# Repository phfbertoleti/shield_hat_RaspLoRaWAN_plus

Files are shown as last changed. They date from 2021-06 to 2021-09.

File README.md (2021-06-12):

# Repositório - Shield/hat RaspLoRaWAN+

Este é o repositório oficial do shield/hat RaspLoRaWAN+. Este sheild/hat fornece à Raspberry Pi, com o uso de um Heltec ESP32 WiFi LoRa, os seguintes recursos:

* Envio (uplink) e recepção (downlink) de mensagens LoRaWAN (já configurado para operar com a rede da ATC no Brasil)
* Leitura de até 3 canais ADC (tensão máxima: 3V3)
* Controle de uma saída analógica (via DAC, com tensão máxima de 3V3)
* Interação com dispositivos (sensores, por exemplo) I²C, com nível de tensão de 3V3
* Escrita, linha a linha, no display OLED do Heltec ESP32 WiFi LoRa

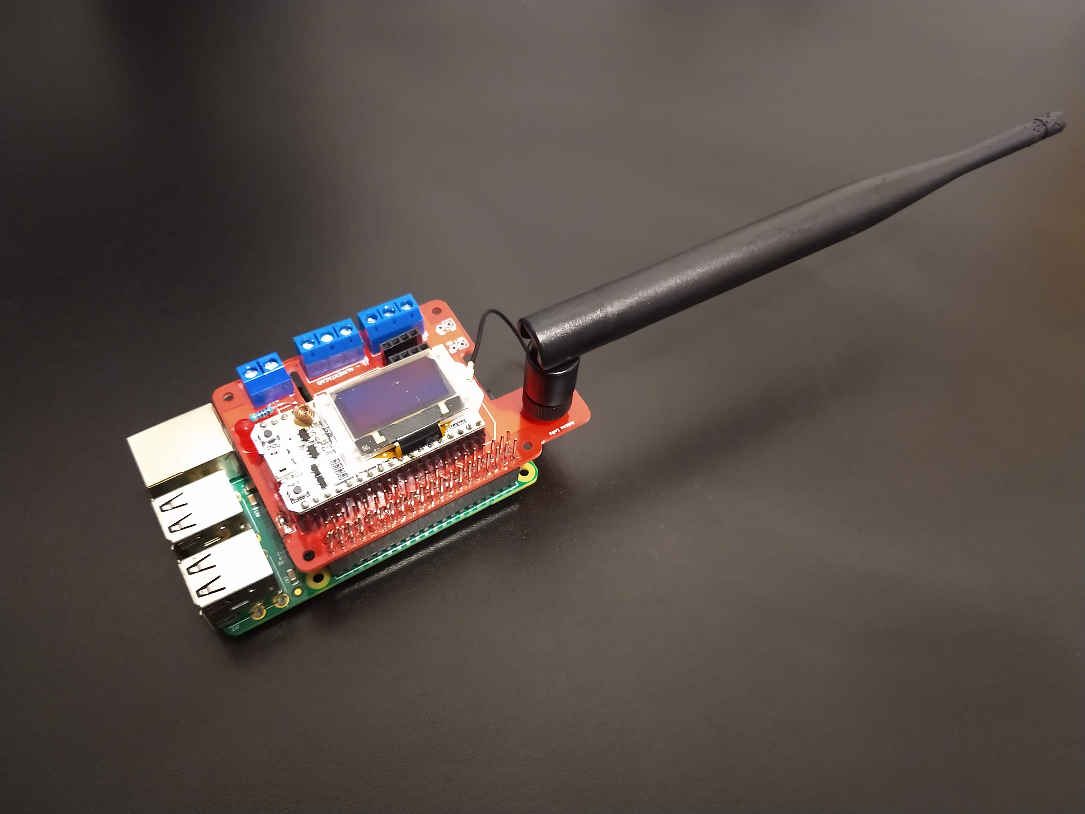
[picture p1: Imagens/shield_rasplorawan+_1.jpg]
Foto do shield/hat RaspLoraWAN+


## Funcionamento e estrutura básica dos códigos-fonte

Este shield/hat funciona com a Raspberry Pi enviando e recebendo mensagens ao Heltec ESP32 WiFi LoRa via UART (115200/8/N/1). Para tal, do lado da Raspberry Pi, é disponível um serviço chamado recebe_envia_dados_uart, totalmente escrito em C para máxima eficiência e otimização. Já do lado do Heltec ESP32 WiFi LoRa, é utilizado um software embarcado escrito na Arduino IDE, fazendo uso de FreeRTOS.

Para interagir com o serviço, é utilizado o protocolo MQTT como IPC (Inter-Processes Communication), com um broker MQTT rodando internamente na Raspberry Pi. Dessa forma, é possível interagir com todas as funcionalidades fazendo publish e subscribe em tópicos MQTT específicos.

A estrutura básica dos códigos-fonte é:

* *Pasta ESP32:* software embarcado a ser gravado no Heltec ESP32 WiFi LoRa. Antes de compilar e gravar, é preciso somente colocar as chaves LoRaWAN no arquivo LORAWAN_defs.h
* *Pasta Raspberry/recebe_envia_dados_uart:* serviço de comunicação UART entre Raspberry Pi e Heltec ESP32 WiFi LoRa, assim como IPC com MQTT
* *Pasta Raspberry/unit_files:* unit files para habilitar o serviço no systemd
* *Pasta Raspberry/Exemplos_Python:* exemplos (em Python 3.X) que exploram todos os recursos da placa
* *Pasta Hardware:* projeto completo (esquemático, layout e gerber files) de hardware do shield/hat

## Compatibilidade

Este shield/hat e seu respectivo software é compatível com todas Raspberries Pi com header de expansão de 40 pinos, como por exemplo:

* Raspberry Pi 3B
* Raspberry Pi 3B+
* Raspberry Pi Zero
* Raspberry Pi Zero W
* Raspberry Pi 4
* Raspberry Pi A+
* etc.

## Instalação dos softwares necessários na Raspberry Pi

Para instalar todos os softwares e dependências necessários na Raspberry Pi, siga o procedimento abaixo:

1. Se sua Raspberry Pi não possuir acesso à Internet, faça-a ter. 
Isso é necessário para a instalação das dependências.
2. Clone este repositório no home (/home/pi)
3. Na pasta do repositório, execute o script instala_tudo.sh como super-usuário:

```
sudo instala_tudo.sh
```

4. Aguarde a instalação automática. No fim do processo, o serviço que comunica com o shield/hat via UART e demais processos (IPC) via MQTT estará rodando. Para verificar a execução deste serviço, utilize o comando abaixo:

```
sudo systemctl status recebe_envia_esp32.service
```

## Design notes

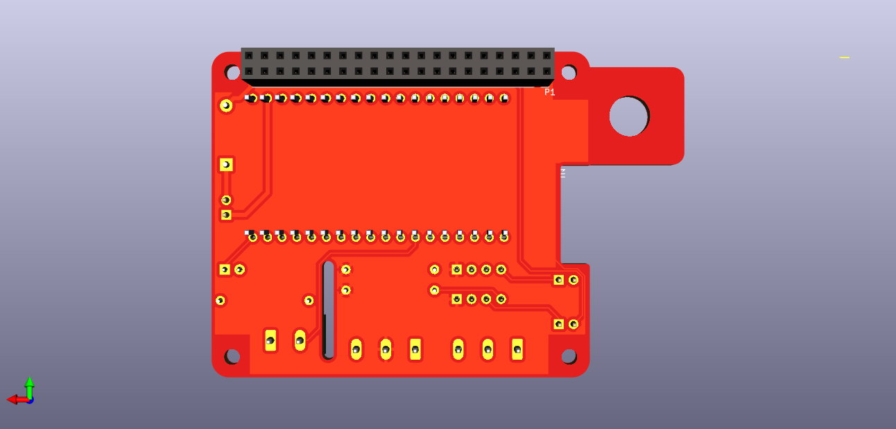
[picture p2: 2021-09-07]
Hardware/rasp_heltec_lora_hat/pcd_3d/rasp_heltec_lora_hat_bottom.png

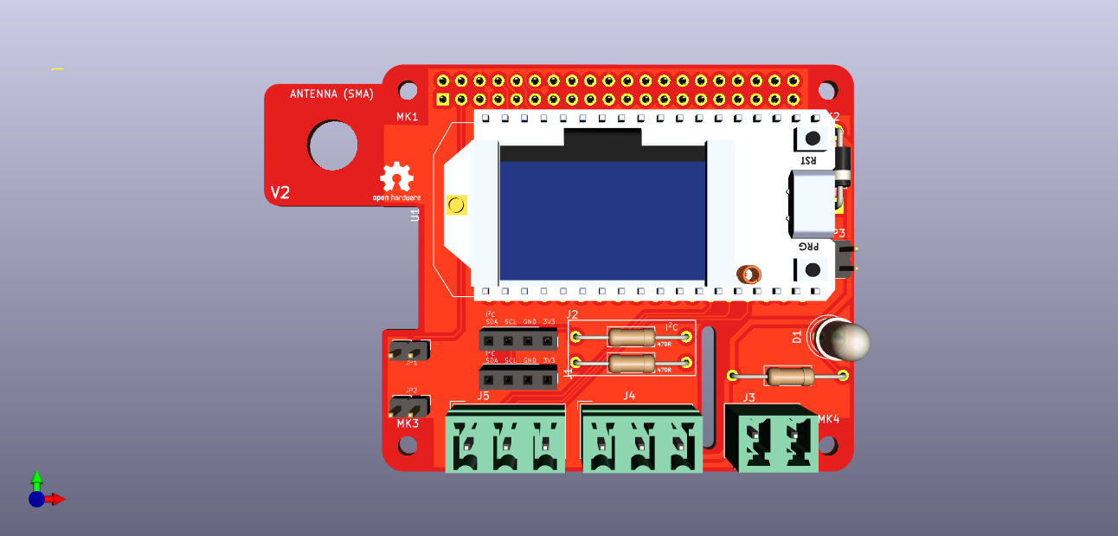
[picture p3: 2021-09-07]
Hardware/rasp_heltec_lora_hat/pcd_3d/rasp_heltec_lora_hat_top.png

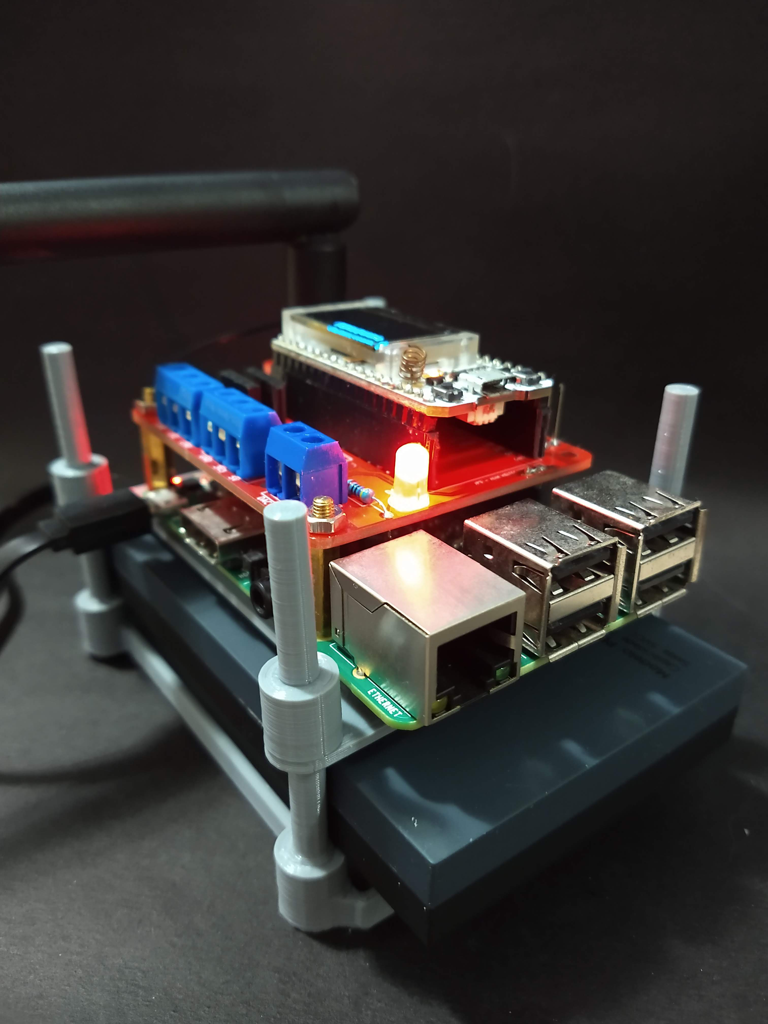
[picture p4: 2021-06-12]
Imagens/sheild_rasplorawan+_2.jpg

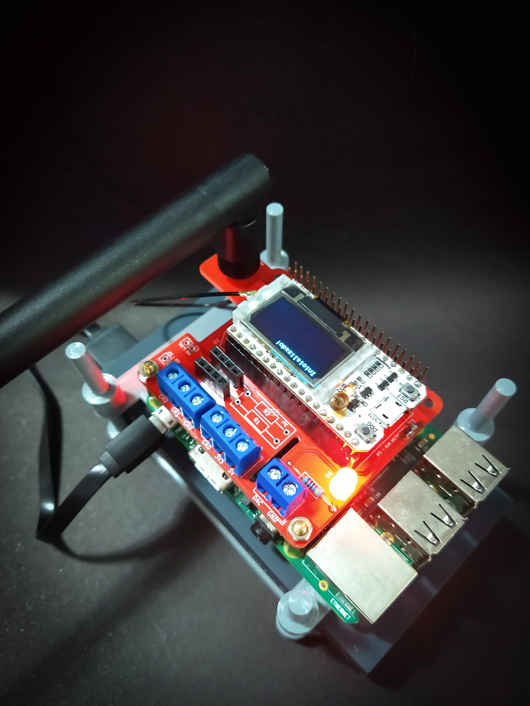
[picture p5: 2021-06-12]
Imagens/sheild_rasplorawan+_4.jpg

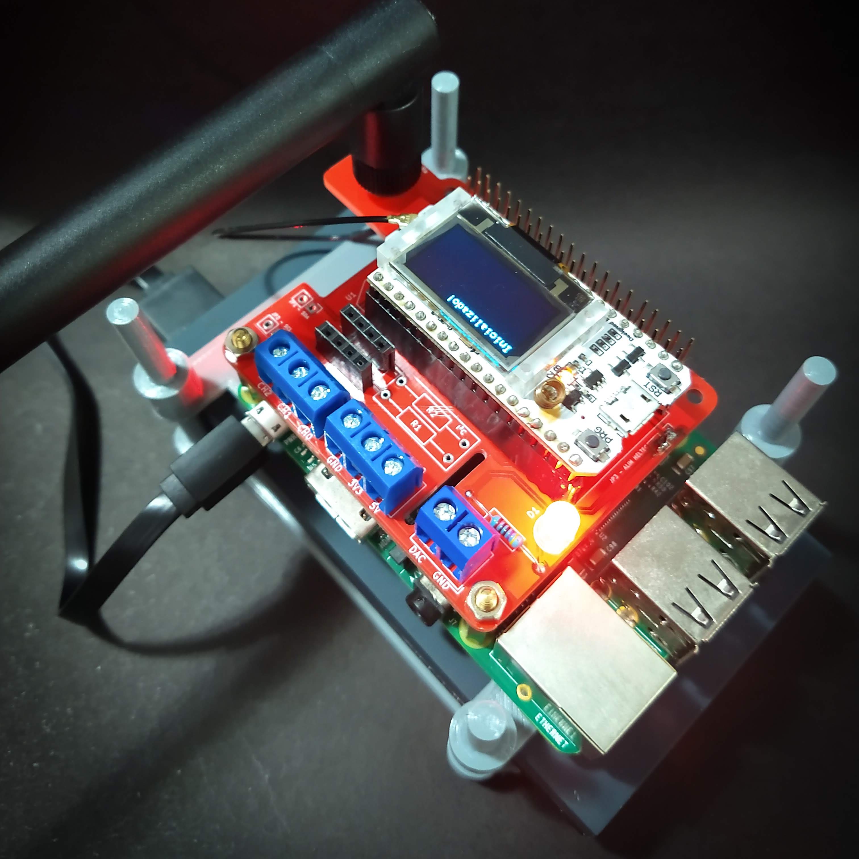
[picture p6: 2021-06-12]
Imagens/sheild_rasplorawan+_5.jpg

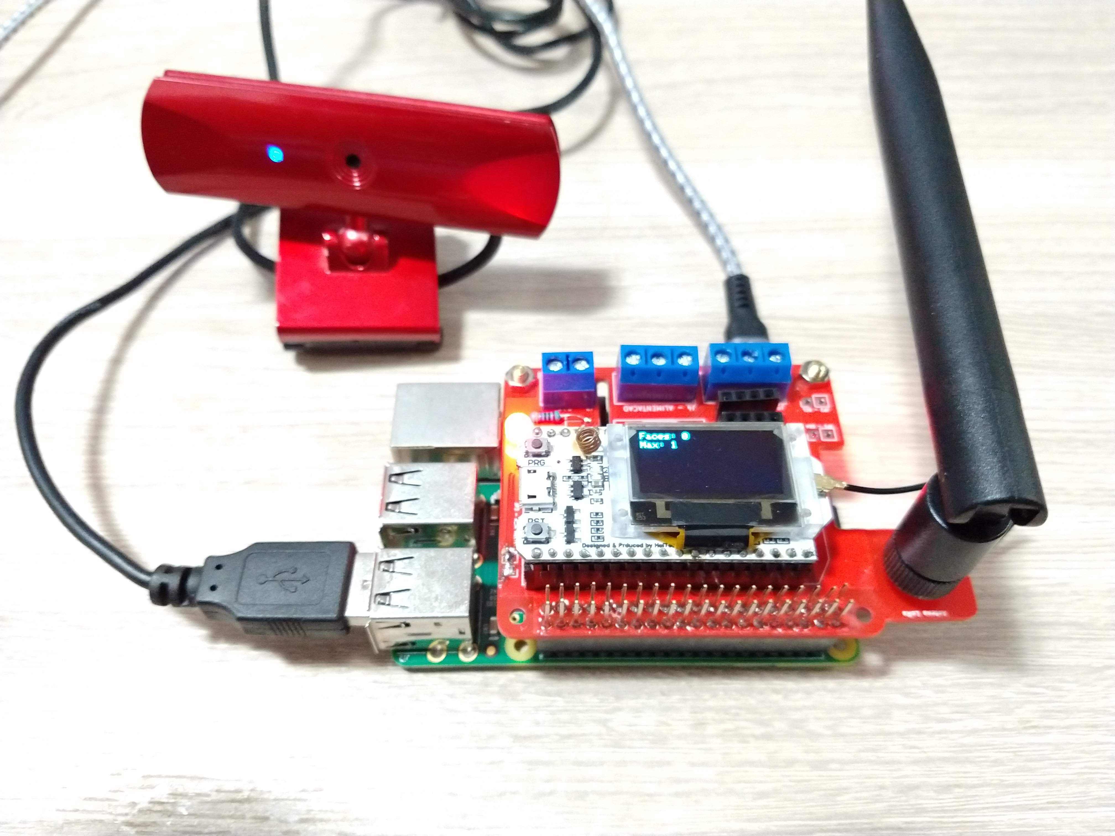
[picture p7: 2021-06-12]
Imagens/shield_rasplorawan+_webcam.jpg

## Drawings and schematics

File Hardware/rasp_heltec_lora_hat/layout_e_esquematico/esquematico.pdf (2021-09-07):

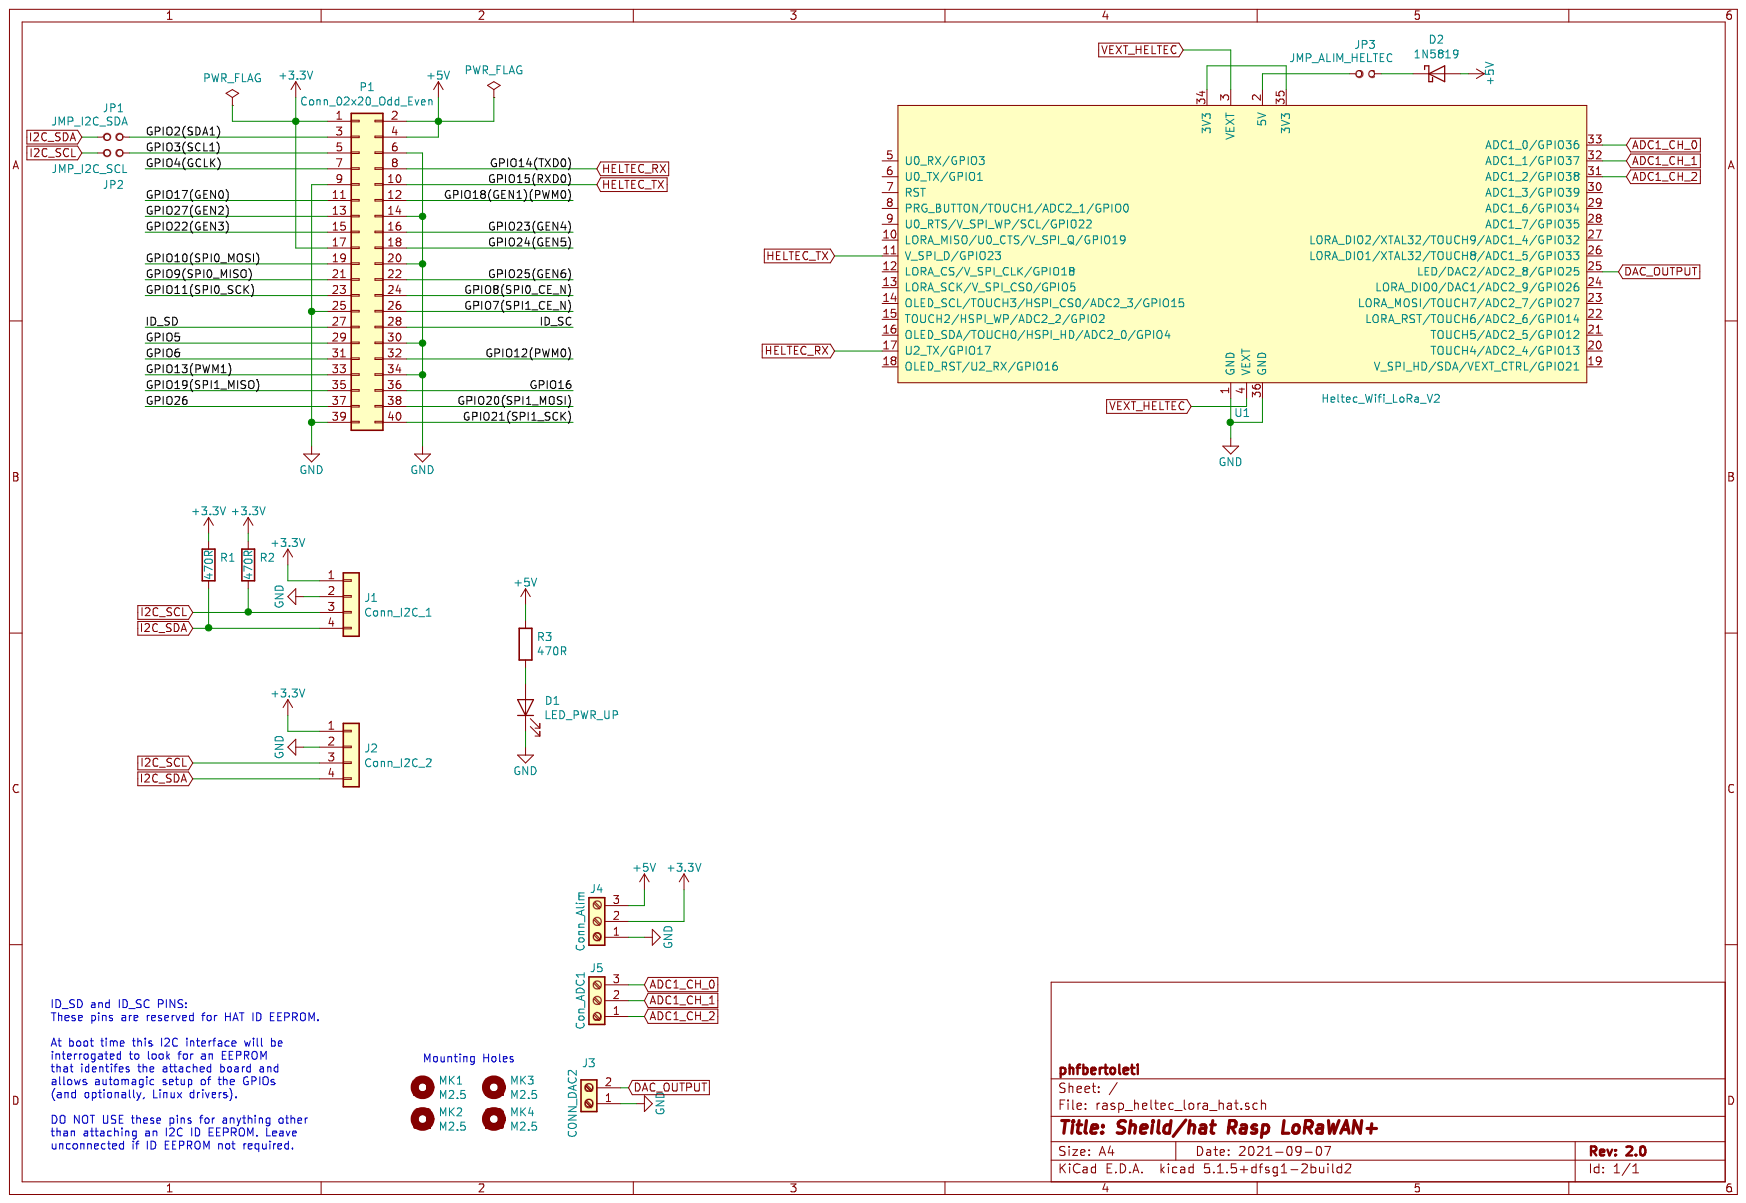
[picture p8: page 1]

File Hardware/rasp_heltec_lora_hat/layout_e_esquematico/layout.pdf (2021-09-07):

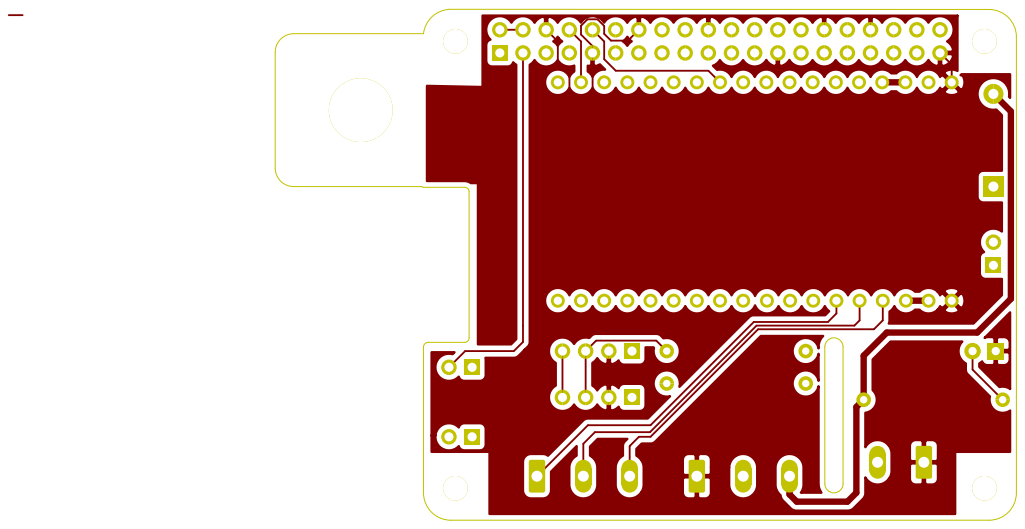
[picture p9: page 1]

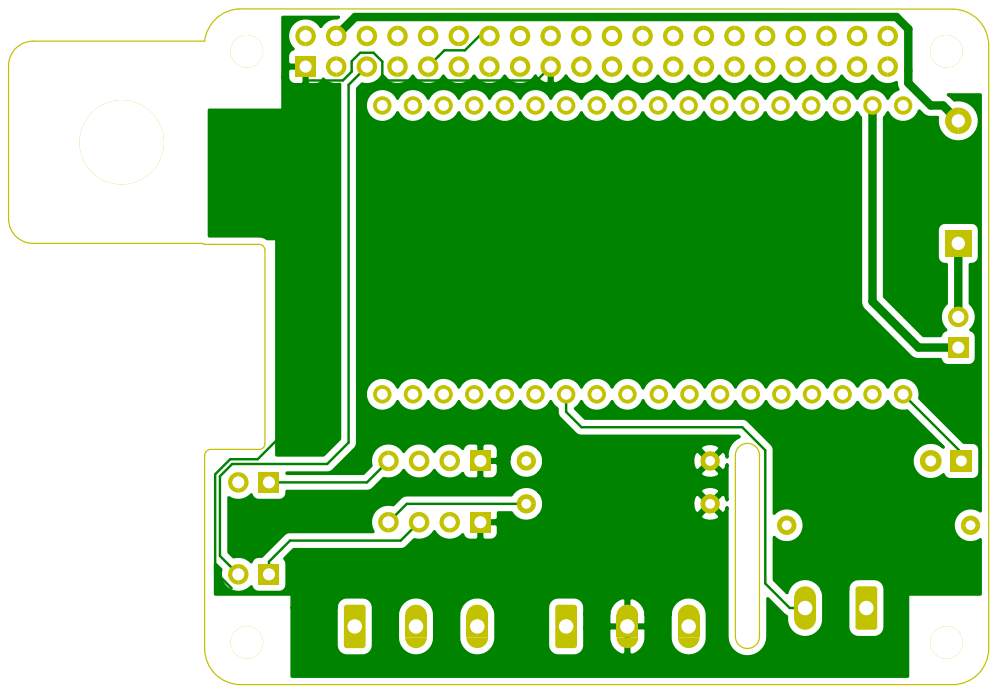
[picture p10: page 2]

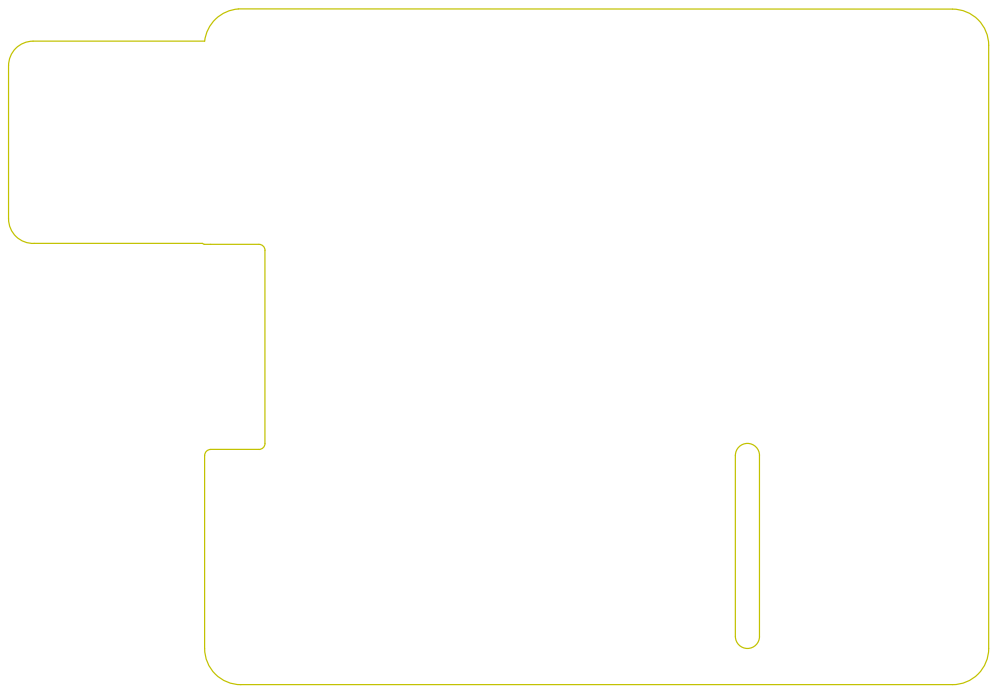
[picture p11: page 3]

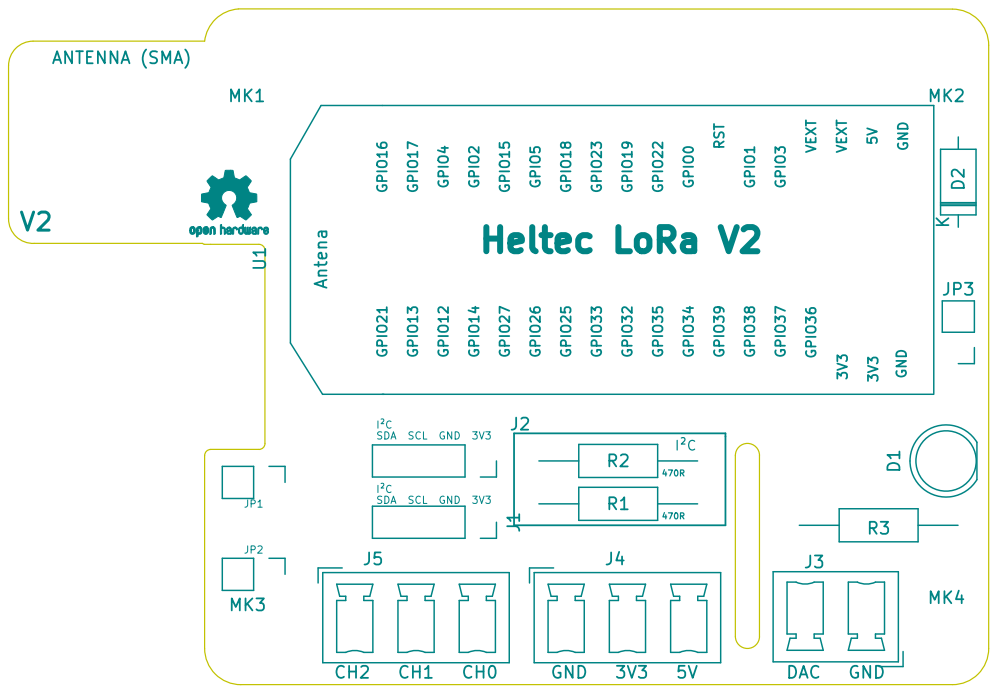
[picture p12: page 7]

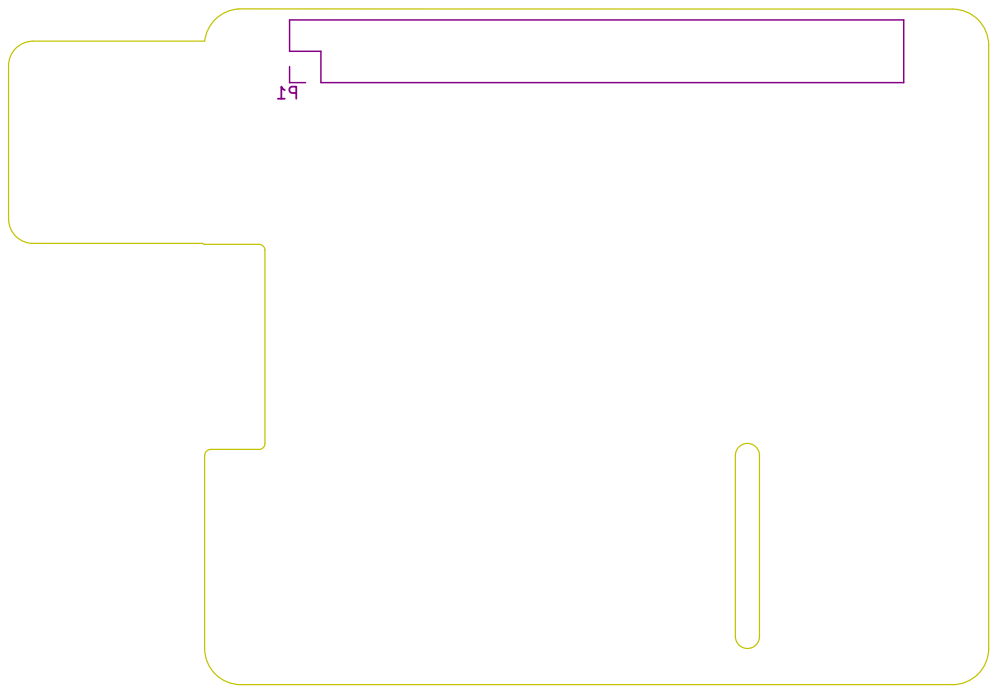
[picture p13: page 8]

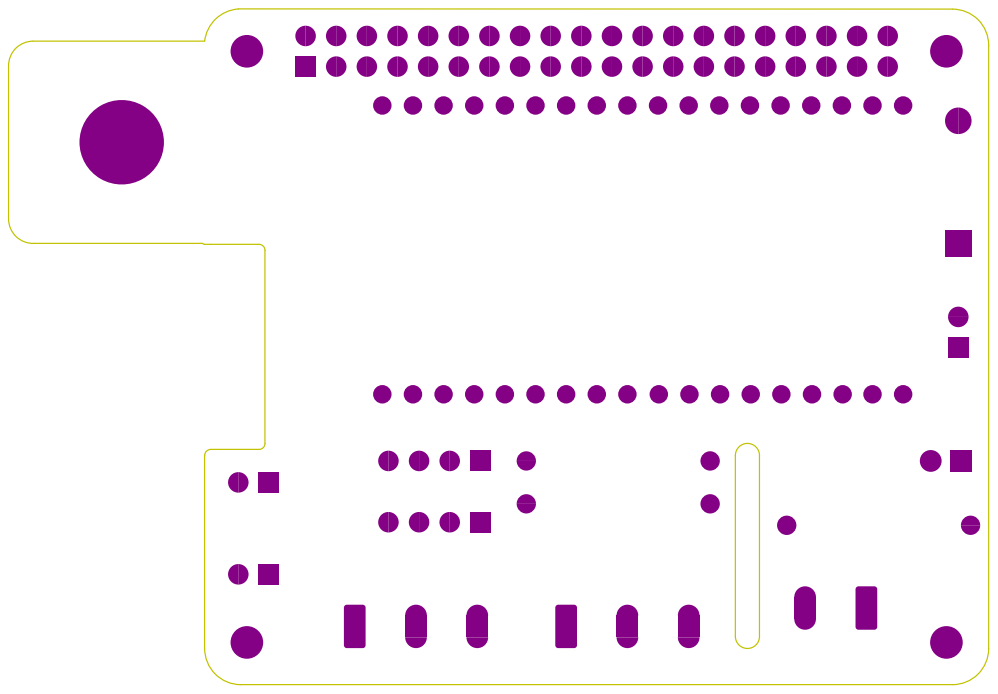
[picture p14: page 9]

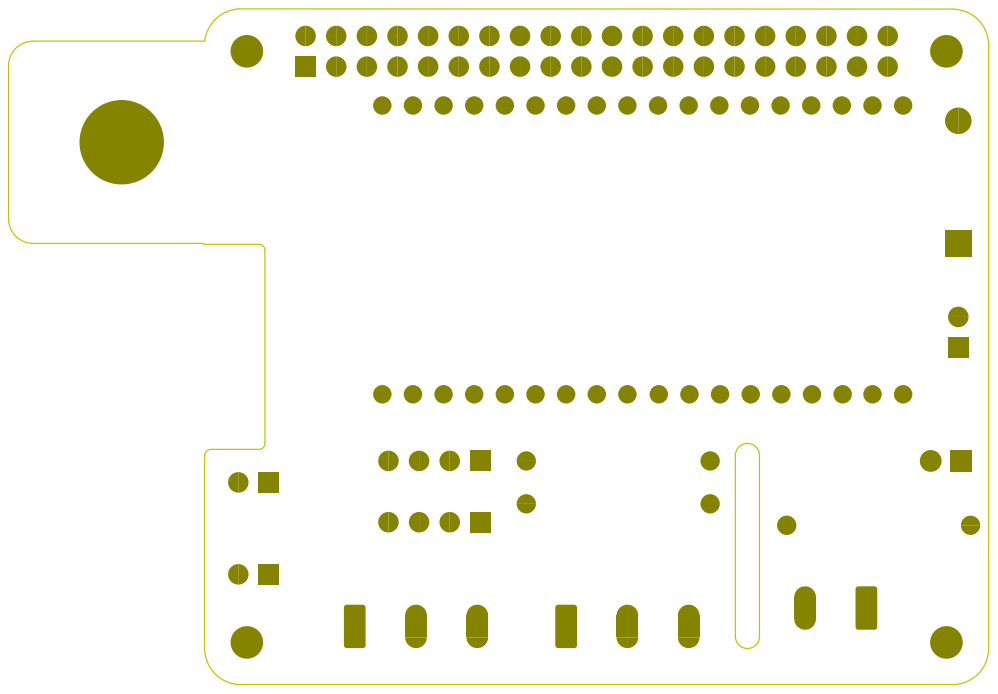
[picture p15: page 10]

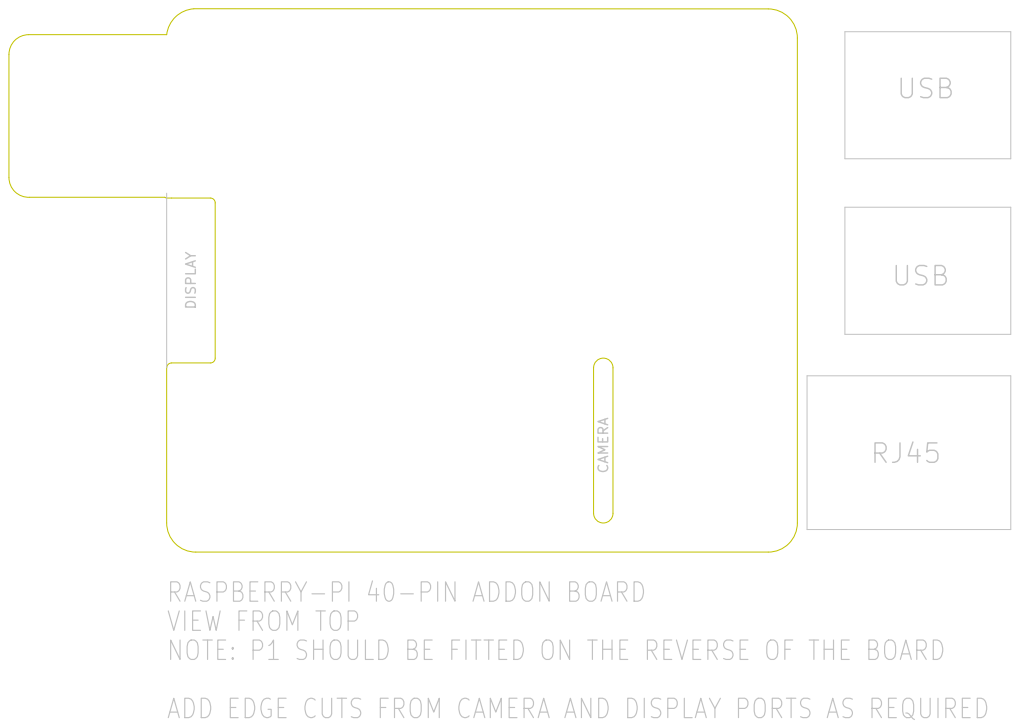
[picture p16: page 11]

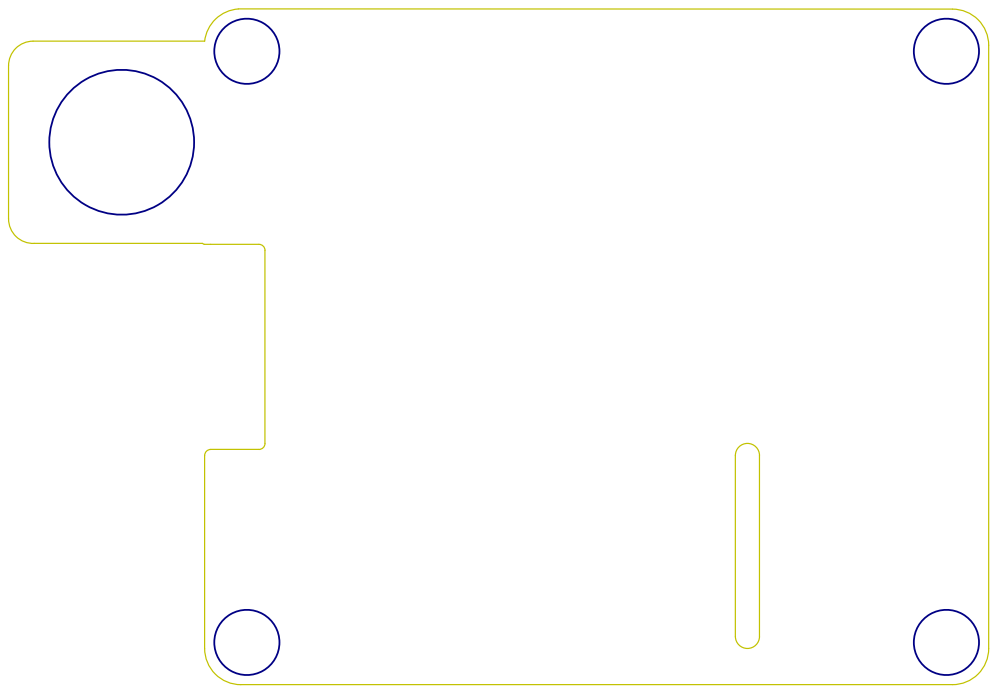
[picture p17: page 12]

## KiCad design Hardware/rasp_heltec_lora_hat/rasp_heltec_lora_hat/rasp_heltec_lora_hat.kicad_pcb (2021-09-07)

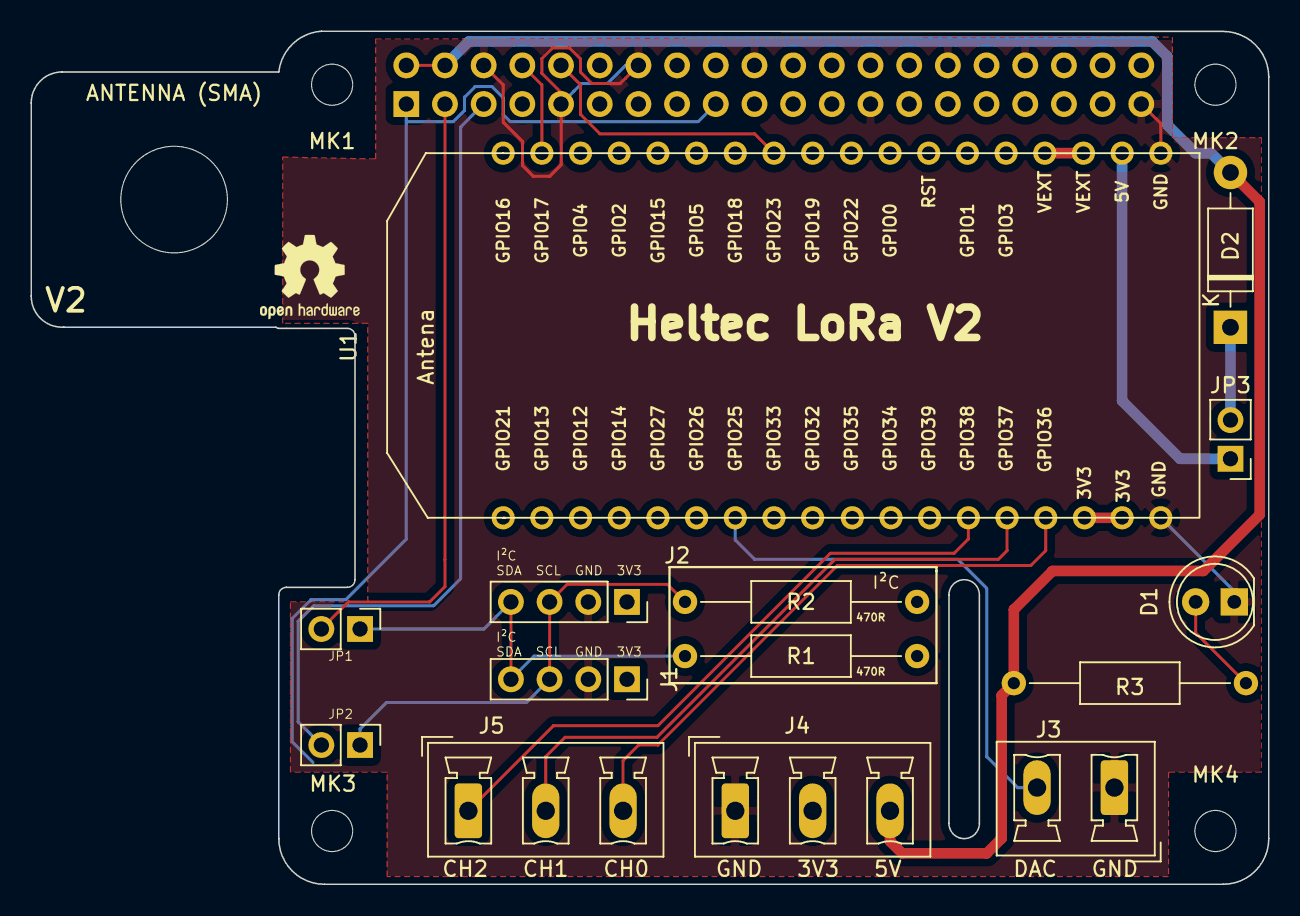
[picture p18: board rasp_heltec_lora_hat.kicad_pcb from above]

Board: 2 copper layers, 81.3 x 56.0 mm, 20 parts (1 on the bottom side), 18 nets.

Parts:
ANTENNA (SMA): MountingHole_6mm
D1: LED_PWR_UP; LED_D5.0mm_Clear
D2: 1N5819; D_DO-41_SOD81_P10.16mm_Horizontal
J1: Conn_I2C_1; PinSocket_1x04_P2.54mm_Vertical
J2: Conn_I2C_2; PinSocket_1x04_P2.54mm_Vertical
J3: CONN_DAC2; PhoenixContact_MCV_1,5_2-G-5.08_1x02_P5.08mm_Vertical
J4: Conn_Alim; PhoenixContact_MCV_1,5_3-G-5.08_1x03_P5.08mm_Vertical
J5: Con_ADC1; PhoenixContact_MCV_1,5_3-G-5.08_1x03_P5.08mm_Vertical
JP1: JMP_I2C_SDA; PinHeader_1x02_P2.54mm_Vertical
JP2: JMP_I2C_SCL; PinHeader_1x02_P2.54mm_Vertical
JP3: JMP_ALIM_HELTEC; PinHeader_1x02_P2.54mm_Vertical
MK1, MK2, MK3, MK4: M2.5; MountingHole_2.7mm_M2.5
P1: Conn_02x20_Odd_Even; PinSocket_2x20_P2.54mm_Vertical
R1, R2, R3: 470R; R_Axial_DIN0207_L6.3mm_D2.5mm_P15.24mm_Horizontal
U1: Heltec_Wifi_LoRa_V2; Heltec_WiFi_LoRa_V2

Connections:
+3V3: J1.1, J2.1, J4.2, P1.1, P1.17, R1.1, R2.1
+5V: D2.2, J4.3, P1.2, P1.4, R3.1
/GPIO2(SDA1): JP1.2, P1.3
/GPIO3(SCL1): JP2.2, P1.5
ADC1_CH_0: J5.3, U1.33
ADC1_CH_1: J5.2, U1.32
ADC1_CH_2: J5.1, U1.31
DAC_OUTPUT: J3.2, U1.25
GND: D1.1, J1.2, J2.2, J3.1, J4.1, P1.6, P1.9, P1.14, P1.20, P1.25, P1.30, P1.34, P1.39, U1.1, U1.36
HELTEC_RX: P1.8, U1.17
HELTEC_TX: P1.10, U1.11
I2C_SCL: J1.3, J2.3, JP2.1, R2.2
I2C_SDA: J1.4, J2.4, JP1.1, R1.2
unnamed: D1.2, R3.2
unnamed: D2.1, JP3.2
unnamed: JP3.1, U1.2
unnamed: U1.34, U1.35
VEXT_HELTEC: U1.3, U1.4

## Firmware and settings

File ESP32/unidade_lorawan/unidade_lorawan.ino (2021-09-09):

/* Programa: unidade lorawan do projeto
 * Autor: Pedro Bertoleti
 */
#include <driver/adc.h>
#include <esp_adc_cal.h> 
#include <freertos/FreeRTOS.h>
#include <freertos/task.h>
#include <esp_task_wdt.h>
#include <lmic.h>
#include <hal/hal.h>
#include <SPI.h>
#include <Adafruit_GFX.h>
#include <Adafruit_SSD1306.h>
#include "FILAS_defs.h"
#include "RADIO_LORA_defs.h"
#include "recepcao_defs.h"
#include "maquina_estados_defs.h"
#include "LORAWAN_defs.h"
#include "PRIOS_defs.h"
#include "STACKS_SIZE_defs.h"
#include "serial_rasppi.h"
#include "SEMAFOROS_defs.h"
#include "DAC_defs.h"
#include "OLED_defs.h"
#include "imagens_defs.h"

/* Definição - tempo máximo sem alimentar o watchdog */
#define TEMPO_WATCHDOG_SEGUNDOS    60

/* Constantes do rádio LoRa: GPIOs utilizados para comunicação
   com rádio SX1276 */
const lmic_pinmap lmic_pins = {
  .nss = RADIO_NSS_PORT,
  .rxtx = LMIC_UNUSED_PIN,
  .rst = RADIO_RESET_PORT,
  .dio = {RADIO_DIO_0_PORT, RADIO_DIO_1_PORT, LMIC_UNUSED_PIN},  //dio2 não é utilizado.
};

/* Objeto para envio e recepção LoRaWAN (ABP) */
static osjob_t sendjob;

/* Estrutura que contem as informacoes para calibracao do ADC */
esp_adc_cal_characteristics_t adc_cal;

/* Array com todos tipos de dados permitidos */
const char tipos_de_dados[TOTAL_TIPO_DADOS] = {TIPO_DADO_LORAWAN_RECEBIDO_OU_ESCRITO,
                                               TIPO_DADO_ESCRITA_DAC,
                                               TIPO_DADO_LEITURA_ADC,
                                               TIPO_DADO_OLED_LINHA_1,
                                               TIPO_DADO_OLED_LINHA_2,
                                               TIPO_DADO_OLED_LINHA_3,
                                               TIPO_DADO_OLED_LINHA_4,
                                               TIPO_DADO_OLED_LINHA_5,
                                               TIPO_DADO_OLED_LINHA_6 };

/* Variável com header dos dados recebidos */
THeader_dados header_dados;

/* Total de bytes a receber */
unsigned char tamanho_a_receber = 0;

/* Array de dados recebidos */
unsigned char array_dados[TAMANHO_MAXIMO_DADOS] = {0};

/* Ponteiro para o array de dados */
unsigned char * pt_dados = NULL;

/* Protótipos de funções auxiliares */
char calcula_checksum(unsigned char * pt_dados, int qtde_bytes);
int verifica_se_tipo_de_dados_eh_valido(char tipo_recebido);
bool maquina_estados_recepcao(uint8_t byte_recebido);
void escreve_serial_debug(char * ptr_string);
void do_send(osjob_t* j, unsigned long total, unsigned long parcial);
void configura_adc(void);

/* Prototipos das tarefas */
void task_oled( void *pvParameters );
void task_serial_rasppi( void *pvParameters );
void task_envio_lorawan( void *pvParameters );

/*
 * Implementações
 */
 
/* Função: calcula o checksum dos dados a serem enviados
 * Parâmetros: ponteiro para os dados e quantidade de bytes para considerar no cálculo
 * Retorno: checksum calculado
 */
char calcula_checksum(unsigned char * pt_dados, int qtde_bytes)
{
    char soma_bytes = 0;
    char cks_calculado;
    int i;

    for (i=0; i<qtde_bytes; i++)
    {
        soma_bytes = soma_bytes + *pt_dados;
        pt_dados++;
    }

    cks_calculado = (~soma_bytes) + 1;
    return cks_calculado;
}

/* Função: verifica se o tipo de dados recebido é válido ou não
 * Parâmetros: tipo de dados recebido
 * Retorno: 0: válido
 *          -1: inválido
 */
int verifica_se_tipo_de_dados_eh_valido(char tipo_recebido)
{
    int resultado = -1;
    int i;
    
    for(i=0; i<TOTAL_TIPO_DADOS; i++)
    {
        if ( tipo_recebido == tipos_de_dados[i])
        {
            resultado = 0;
            break;
        }
    }

    return resultado;
}

/* Função: máquina de estados de recepcao de pacotes LoRa
 * Parâmetros: byte recebido
 * Retorno: true: recepção de um pacote completo
 *          false: recepção de pacote está incompleta
 */
bool maquina_estados_recepcao(uint8_t byte_recebido)
{
    bool recepcao_completa = false;
    char checksum_recebido = 0x00;
    char cks_calculado = 0x00;
    char linha_debug[100];

    switch (estado_recepcao)
    {
        case ESTADO_BYTE_SINCRONIA_1:
            escreve_serial_debug("Estado: ESTADO_BYTE_SINCRONIA_1");
            if (byte_recebido == BYTE_SINCRONIA_1)
            {
                header_dados.byte_sincronia_1 = byte_recebido;
                estado_recepcao = ESTADO_BYTE_SINCRONIA_2;
            }
            break;

        case ESTADO_BYTE_SINCRONIA_2:
            escreve_serial_debug("Estado: ESTADO_BYTE_SINCRONIA_2");
            if (byte_recebido == BYTE_SINCRONIA_2)
            {
                header_dados.byte_sincronia_2 = byte_recebido;
                estado_recepcao = ESTADO_BYTE_SINCRONIA_3;
            }
            else
                estado_recepcao = ESTADO_BYTE_SINCRONIA_1;
            break;

        case ESTADO_BYTE_SINCRONIA_3:
            escreve_serial_debug("Estado: ESTADO_BYTE_SINCRONIA_3");
            if (byte_recebido == BYTE_SINCRONIA_3)
            {
                header_dados.byte_sincronia_3 = byte_recebido;
                estado_recepcao = ESTADO_BYTE_SINCRONIA_4;
            }
            else
                estado_recepcao = ESTADO_BYTE_SINCRONIA_1;

            break;

        case ESTADO_BYTE_SINCRONIA_4:
            escreve_serial_debug("Estado: ESTADO_BYTE_SINCRONIA_4");
            if (byte_recebido == BYTE_SINCRONIA_4)
            {
                header_dados.byte_sincronia_4 = byte_recebido;
                estado_recepcao = ESTADO_BYTE_SINCRONIA_5;
            }
            else
                estado_recepcao = ESTADO_BYTE_SINCRONIA_1;

            break;

        case ESTADO_BYTE_SINCRONIA_5:
            escreve_serial_debug("Estado: ESTADO_BYTE_SINCRONIA_5");
            if (byte_recebido == BYTE_SINCRONIA_5)
            {
                header_dados.byte_sincronia_5 = byte_recebido;
                estado_recepcao = ESTADO_BYTE_SINCRONIA_6;
            }
            else
                estado_recepcao = ESTADO_BYTE_SINCRONIA_1;

            break;

        case ESTADO_BYTE_SINCRONIA_6:
            escreve_serial_debug("Estado: ESTADO_BYTE_SINCRONIA_6");
            if (byte_recebido == BYTE_SINCRONIA_6)
            {
                header_dados.byte_sincronia_4 = byte_recebido;
                estado_recepcao = ESTADO_RECEBE_TIPO_DE_DADOS;
            }
            else
                estado_recepcao = ESTADO_BYTE_SINCRONIA_1;

            break;
            
        case ESTADO_RECEBE_TIPO_DE_DADOS:
             escreve_serial_debug("Estado: ESTADO_RECEBE_TIPO_DE_DADOS");
             if (verifica_se_tipo_de_dados_eh_valido(byte_recebido) == 0)
             {
                header_dados.tipo_de_dados = byte_recebido;
                estado_recepcao = ESTADO_RECEBE_TAMANHO;
             }
            else
                estado_recepcao = ESTADO_BYTE_SINCRONIA_1;
            break;

        case ESTADO_RECEBE_TAMANHO:
            sprintf(linha_debug, "Estado: ESTADO_RECEBE_TAMANHO: %d", (int)byte_recebido);
            escreve_serial_debug(linha_debug);
            
            header_dados.tamanho = (unsigned char)byte_recebido;
            tamanho_a_receber = (unsigned char)byte_recebido;
            memset(array_dados, 0x00, sizeof(array_dados));
            pt_dados = array_dados;
            estado_recepcao = ESTADO_RECEBE_DADOS;
            break;   

        case ESTADO_RECEBE_DADOS:
            escreve_serial_debug("Estado: ESTADO_RECEBE_DADOS");
            
            if (tamanho_a_receber > 0)
            {
                escreve_serial_debug("Byte de dado recebido.");
                *pt_dados = byte_recebido;
                pt_dados++;         
                tamanho_a_receber--;                                       
            }

            if (tamanho_a_receber == 0)
            {
                estado_recepcao = ESTADO_AGUARDA_DADOS_VERIFICA_CKS;
            }

            break;

        case ESTADO_AGUARDA_DADOS_VERIFICA_CKS:
            escreve_serial_debug("Estado: ESTADO_AGUARDA_DADOS_VERIFICA_CKS");
            checksum_recebido = byte_recebido;
            cks_calculado = calcula_checksum(array_dados, (int)header_dados.tamanho);

            if (checksum_recebido ==  cks_calculado)
            {
                escreve_serial_debug("Estado: ESTADO_AGUARDA_DADOS_VERIFICA_CKS: cks ok");                
                recepcao_completa = true;    
            }
            else
            {
                sprintf(linha_debug, "cks falhou! Esperado: %02X; Recebido: %02X", cks_calculado, checksum_recebido);
                escreve_serial_debug(linha_debug);
                recepcao_completa = false;
            }

            estado_recepcao = ESTADO_BYTE_SINCRONIA_1;

            break;
    }

    return recepcao_completa;
}

/*  Funcao: escreve na serial, considerando o semoforo
 *  Parometros: ponteiro para string a ser escrita
 *  Retorno: nenhum
 */
void escreve_serial_debug(char * ptr_string)
{
    if (xSemaphoreTake(xSerial_semaphore, TICKS_ESPERA_SEMAFORO_SERIAL ) == pdTRUE)
    {
        Serial.println(ptr_string);
        xSemaphoreGive(xSerial_semaphore);
    }
}

/* Callbacks para uso cpm OTAA apenas (por este projeto usar ABP, isso, eles 
 *  estão vazios) */
void os_getArtEui (u1_t* buf) 
{ 
    /* Não utilizado neste projeto */  
}

void os_getDevEui (u1_t* buf) 
{ 
    /* Não utilizado neste projeto */  
}

void os_getDevKey (u1_t* buf) 
{ 
    /* Não utilizado neste projeto */  
}

/* Callback de evento: todo evento do LoRaWAN irá chamar essa
   callback, de forma que seja possível saber o status da 
   comunicação com o gateway LoRaWAN. */
void onEvent (ev_t ev) 
{
    char cks_calculado;
    char array_downlink[TAMANHO_MAXIMO_DADOS+1] = {0};
    
    switch(ev) 
    {
        case EV_SCAN_TIMEOUT:
            break;
        case EV_BEACON_FOUND:
            break;
        case EV_BEACON_MISSED:
            break;
        case EV_BEACON_TRACKED:
            break;
        case EV_JOINING:
            break;
        case EV_JOINED:
            break;
        case EV_JOIN_FAILED:
            break;
        case EV_REJOIN_FAILED:
            break;
        case EV_TXCOMPLETE:
            escreve_serial_debug("EV_TXCOMPLETE (incluindo espera pelas janelas de recepção)");

            /* Verifica se ack foi recebido do gateway */
            if (LMIC.txrxFlags & TXRX_ACK)
              escreve_serial_debug("Ack recebido");

            /* Verifica se foram recebidos dados do gateway */  
            if (LMIC.dataLen > 0) 
            {
                escreve_serial_debug("Recebidos bytes (downlink)");
                array_downlink[0] = (char)LMIC.dataLen;
                memcpy(array_downlink+1, LMIC.frame + LMIC.dataBeg, (char)LMIC.dataLen);
                xQueueSend( xQueue_lorawan_downlink, (void *) &array_downlink, TICKS_ESPERA_ESCRITA_FILAS);
            }

            /* Devolve o controle do semáforo da serial */
            xSemaphoreGive(xSerial_semaphore);
            
            break;

        case EV_LOST_TSYNC:
            break;
        case EV_RESET:
            break;
        case EV_RXCOMPLETE:
            break;
        case EV_LINK_DEAD:
            break;
        case EV_LINK_ALIVE:
            break;
        case EV_TXSTART:            
            break;
        default:
            break;
    }
}

/* Função para envio de dados ao gateway LoRaWAN */
void do_send(osjob_t* j, unsigned char * pt_dados)
{
    static uint8_t mydata[TAMANHO_MAXIMO_DADOS+1];
    unsigned char tamanho_dados;

    esp_task_wdt_reset();

    /* Le tamanho dos dados e o copia para array mydata */
    tamanho_dados = *pt_dados;
    pt_dados++;
    memcpy(mydata, pt_dados, tamanho_dados);
    
    /* Verifica se já há um envio sendo feito.
       Em caso positivo, o envio atual é suspenso. */
    if (LMIC.opmode & OP_TXRXPEND) 
    {
        escreve_serial_debug("OP_TXRXPEND: ha um envio ja pendente, portanto o envio atual nao sera feito");
    } 
    else 
    {
        /* Aqui, o envio pode ser feito. */
        /* O pacote LoRaWAN é montado e o coloca na fila de envio. */
        LMIC_setTxData2(4, mydata, tamanho_dados, ENVIO_SEM_CONFIRMACAO);
        escreve_serial_debug("Pacote LoRaWAN na fila de envio."); 
    }
    
    esp_task_wdt_reset();
}

/* Função: configura ADC para leitura de tensão (tensao max: 3,9V)
 * Parâmetros: nenhum
 * Retorno:  nenhum
 */
void configura_adc(void)
{
    adc1_config_width(ADC_WIDTH_BIT_12);
    adc1_config_channel_atten(ADC1_CHANNEL_0,ADC_ATTEN_DB_11);
    adc1_config_channel_atten(ADC1_CHANNEL_1,ADC_ATTEN_DB_11);
    adc1_config_channel_atten(ADC1_CHANNEL_2,ADC_ATTEN_DB_11);
    esp_adc_cal_value_t adc_type = esp_adc_cal_characterize(ADC_UNIT_1, ADC_ATTEN_DB_11, ADC_WIDTH_BIT_12, 1100, &adc_cal);
}

void setup() 
{
    int tamanho_item_fila;

    /* Inicialização da serial de bebug */
    Serial.begin(115200);

    /* Inicializacao da serial de configuracao */
    Serial1.begin(SERIAL_RASPPI_BAUDRATE,
                  SERIAL_RASPPI_BITS_E_PARIDADE,
                  SERIAL_RASPPI_RX,
                  SERIAL_RASPPI_TX);

    /* Configura ADC para uso */
    configura_adc();

    /* Inicializa display */
    Wire.begin(OLED_SDA_PIN, OLED_SCL_PIN);
    if(!display.begin(SSD1306_SWITCHCAPVCC, OLED_ADDRESS)) 
    { 
        Serial.println("[ERRO] não foi possivel inicializar display. O ESP32 será reiniciado em 1s...");
        delay(1000);
        ESP.restart();
    }
    else
    {
        Serial.println("Display inicializado.");
        
        display.clearDisplay();
        display.drawBitmap(0, 0, lorawan_logo, 128, 64, WHITE);
        display.display();        
    }
    
    /* Criacao dos semaforos */
    xSerial_semaphore = xSemaphoreCreateMutex();
  
    if (xSerial_semaphore == NULL)
    {
        Serial.println("[ERRO] Nao e possivel criar um ou mais semaforos. ESP32 reiniciara em 1s...");
        delay(1000);
        ESP.restart();
    }

    /* Criacao das filas  */
    tamanho_item_fila = sizeof(THeader_dados) + TAMANHO_MAXIMO_DADOS + 1; //+1 devido ao byte de tamanho
    xQueue_dados_lorawan = xQueueCreate(TAMANHO_FILA_DADOS_LORAWAN_DOWNLINK, tamanho_item_fila);  
    xQueue_lorawan_downlink = xQueueCreate(TAMANHO_FILA_DADOS_LORAWAN_UPLINK, tamanho_item_fila);
    xQueue_display = xQueueCreate(1, sizeof( TTela_display ));

    if ( (xQueue_dados_lorawan == NULL) || (xQueue_lorawan_downlink == NULL) || (xQueue_display == NULL) )
    {
        Serial.println("[ERRO] Nao e possivel criar uma ou mais filas. ESP32 reiniciara em 1s...");
        delay(1000);
        ESP.restart();
    }

    /* Inicia o Task WDT */
    esp_task_wdt_init(TEMPO_WATCHDOG_SEGUNDOS, true); 

    /* Criação das tarefas */
    xTaskCreate(
    task_serial_rasppi               
    , "serial"                     
    ,  STACK_SIZE_SERIAL_RASPPI      
    ,  NULL                       
    ,  PRIO_SERIAL_RASPPI     
    ,  NULL);                    

    /* Criação das tarefas */
    xTaskCreatePinnedToCore(
    task_oled               
    , "task_oled"                     
    ,  STACK_SIZE_OLED      
    ,  NULL                       
    ,  PRIO_OLED     
    ,  NULL
    ,  1);

    xTaskCreate(
    task_envio_lorawan               
    , "lorawan"                     
    ,  STACK_SIZE_LORAWAN      
    ,  NULL                       
    ,  PRIO_LORAWAN     
    ,  NULL);        
}

void loop() 
{
    /* Tudo é gerenciado pelas tarefas. Nada é feito aqui. */
}

/*
 * Implementação das tarefas
 */
/* Tarefa responsável por atualizar display OLED */
void task_oled( void *pvParameters )
{
    TTela_display tela_display;

    /* Habilita o monitoramento do Task WDT nesta tarefa */
    esp_task_wdt_add(NULL); 
            
    while(1)
    {
        /* Escreve as linhas */
        if (xQueueReceive(xQueue_display, (void *)&tela_display, TICKS_ESPERA_LEITURA_FILAS) == pdTRUE) 
        {
            display.clearDisplay();
            display.setTextColor(WHITE);
            display.setCursor(0,OLED_LINHA_1);
            display.println(tela_display.linha1);
            display.setCursor(0,OLED_LINHA_2);
            display.print(tela_display.linha2);
            display.setCursor(0,OLED_LINHA_3);
            display.print(tela_display.linha3);
            display.setCursor(0,OLED_LINHA_4);
            display.print(tela_display.linha4);
            display.setCursor(0,OLED_LINHA_5);
            display.print(tela_display.linha5);
            display.setCursor(0,OLED_LINHA_6);
            display.print(tela_display.linha6);            
            display.display();
        }

        esp_task_wdt_reset();
        vTaskDelay( TEMPO_REFRESH_DISPLAY / portTICK_PERIOD_MS ); 
    }
}
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

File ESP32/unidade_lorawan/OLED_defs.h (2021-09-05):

/* Header file - display OLED */

#ifndef OLED_DEFS_H
#define OLED_DEFS_H

/* Definições - OLED */
#define OLED_CLEAR_LINE         "                     "
#define OLED_LINE_MAX_SIZE      21
#define OLED_SDA_PIN            4
#define OLED_SCL_PIN            15
#define OLED_ADDRESS            0x3C
#define OLED_RESET              16 
#define OLED_SCREEN_HEIGHT      64
#define OLED_SCREEN_WIDTH       128
#define OLED_LINHA_1            0
#define OLED_LINHA_2            10
#define OLED_LINHA_3            20
#define OLED_LINHA_4            30
#define OLED_LINHA_5            40
#define OLED_LINHA_6            50
#define TEMPO_REFRESH_DISPLAY   500 //ms

/* Estrutura que contem cada linha que pode ser escrita no display OLED da placa */
typedef struct
{
    char linha1[OLED_LINE_MAX_SIZE];
    char linha2[OLED_LINE_MAX_SIZE];
    char linha3[OLED_LINE_MAX_SIZE];
    char linha4[OLED_LINE_MAX_SIZE];
    char linha5[OLED_LINE_MAX_SIZE];
    char linha6[OLED_LINE_MAX_SIZE];
}TTela_display;

#endif

Adafruit_SSD1306 display(OLED_SCREEN_WIDTH, 
                         OLED_SCREEN_HEIGHT, 
                         &Wire, 
                         OLED_RESET, 
                         100000UL, 
                         100000UL);

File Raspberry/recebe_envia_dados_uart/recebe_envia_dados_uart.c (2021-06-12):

/*  Serviço: recepcao e envio de dados para o ESP32 (Heltec ESP32 WiFi LoRa) e 
 *           IPC (via MQTT)
 *  Autor: Pedro Bertoleti
 */
#include <stdio.h>
#include <stdlib.h>
#include <string.h>
#include <fcntl.h> 
#include <termios.h>
#include <unistd.h>
#include <errno.h> 
#include <stdint.h>
#include <stdbool.h>
#include <sys/stat.h>
#include <sys/types.h>
#include <MQTTClient.h>
#include "comunicacao_uart.h"
#include "trata_e_envia_dados_lora.h"
#include "debug_defs.h"
#include "dados_defs.h"
#include "recepcao_defs.h"
#include "mqtt_defs.h"

/* File descriptor da UART */
int fd;

/* Ponteiro para array de dados a serem escritos na UART */
uint8_t * pt_dados_para_escrever_uart = NULL;

/* Variável para controlar o client MQTT */
MQTTClient client;

/* Protótipos locais */
int on_message(void *context, char *topic_name, int topic_length, MQTTClient_message *message);

/* Funcao: publicacao de mensagens MQTT
 * Parametros: cleinte MQTT, topico MQTT and payload
 * Retorno: nenhum
*/
void publish(MQTTClient client, char* topic, char* payload) 
{
    MQTTClient_message pubmsg = MQTTClient_message_initializer;

    pubmsg.payload = payload;
    pubmsg.payloadlen = strlen(pubmsg.payload);
    pubmsg.qos = 0;
    pubmsg.retained = 0;
    MQTTClient_deliveryToken token;
    MQTTClient_publishMessage(client, topic, &pubmsg, &token);
    MQTTClient_waitForCompletion(client, token, 1000L);
}

/* Funcao: callback de mensagens MQTT recebidas e echo para o broker
 * Parametros: contexto, ponteiro para nome do topico da mensagem recebida, tamanho do nome do topico e mensagem recebida
 * Retorno : 1: sucesso (fixo / nao ha checagem de erro neste exemplo)
*/
int on_message(void *context, char *topic_name, int topic_length, MQTTClient_message *message) 
{
    char * payload = message->payload;
    int tamanho_payload = message->payloadlen;
    unsigned char dado_adc;
    int valor_dac = 0;
    char payload_dac_padding[4] = {0};

    /* Mostra a mensagem recebida */
    #ifdef HABILITA_DEBUG_VIA_PRINTF
    printf("Mensagem recebida! \n\rTopico: %s Mensagem: %s\n", topic_name, payload);
    #endif

    /* 
     * Toma ação de acordo com tópico e mensagem recebido 
     */

    /* Envio de dados para ESP32 (para o posterior envio LoRaWAN) */
    if (strcmp(topic_name, MQTT_SUB_DADOS_LORAWAN_UPLINK_PARA_ESP) == 0)
    {
        /* Repassa dados recebidos ao ESP32 */
        envia_dados_esp32((uint8_t *)payload, TIPO_DADO_LORAWAN_RECEBIDO_OU_ESCRITO, tamanho_payload);
    }     
    
    /* Envio de valor do DAC a ser escrito no ESP32 */
    if (strcmp(topic_name, MQTT_SUB_DAC_ESP32) == 0)
    {
        valor_dac = atoi(payload);
        sprintf(payload_dac_padding, "%03d", valor_dac);

        #ifdef HABILITA_DEBUG_VIA_PRINTF
        printf("Valor a ser escrito no DAC: %d\n", valor_dac);
        #endif

        if ( (valor_dac >= 0) &&  (valor_dac <= 255) )
        {            
            envia_dados_esp32((uint8_t *)&payload_dac_padding, TIPO_DADO_ESCRITA_DAC, 4);
        }
    }  

    /* Requisita ao ESP32 a leitura dos 3 canais do ADC */
    if (strcmp(topic_name, MQTT_SUB_ADC_RASPPI) == 0)
    {
        dado_adc = (unsigned char)*payload;
        envia_dados_esp32((uint8_t *)&dado_adc, TIPO_DADO_LEITURA_ADC, 1);
    }    

    /* Envia linha (1..6) a ser escrita no display OLED do Heltec ESP32 WiFi LoRa */
    if (strcmp(topic_name, MQTT_SUB_OLED_LINHA_1) == 0)
    {
        envia_linha_display_oled((uint8_t *)payload, TIPO_DADO_OLED_LINHA_1, tamanho_payload);
    }

    if (strcmp(topic_name, MQTT_SUB_OLED_LINHA_2) == 0)
    {
        envia_linha_display_oled((uint8_t *)payload, TIPO_DADO_OLED_LINHA_2, tamanho_payload);
    }

    if (strcmp(topic_name, MQTT_SUB_OLED_LINHA_3) == 0)
    {
        envia_linha_display_oled((uint8_t *)payload, TIPO_DADO_OLED_LINHA_3, tamanho_payload);
    }

    if (strcmp(topic_name, MQTT_SUB_OLED_LINHA_4) == 0)
    {
        envia_linha_display_oled((uint8_t *)payload, TIPO_DADO_OLED_LINHA_4, tamanho_payload);
    }

    if (strcmp(topic_name, MQTT_SUB_OLED_LINHA_5) == 0)
    {
        envia_linha_display_oled((uint8_t *)payload, TIPO_DADO_OLED_LINHA_5, tamanho_payload);
    }

    if (strcmp(topic_name, MQTT_SUB_OLED_LINHA_6) == 0)
    {
        envia_linha_display_oled((uint8_t *)payload, TIPO_DADO_OLED_LINHA_6, tamanho_payload);
    }


    MQTTClient_freeMessage(&message);
    MQTTClient_free(topic_name);
    return 1;
}

int main (int argc, char *argv[])
{
    uint8_t byte_lido;    
    int rc;
    int qtde_bytes_lidos;
    MQTTClient_connectOptions conn_opts = MQTTClient_connectOptions_initializer;

    /* Aguarda 30 segundos para iniciar serviço */
    system("sleep 30");

    /* Inicializacao do MQTT (conexao & subscribe) */
    MQTTClient_create(&client, MQTT_ADDRESS, MQTT_CLIENTID, MQTTCLIENT_PERSISTENCE_NONE, NULL);
    MQTTClient_setCallbacks(client, NULL, NULL, on_message, NULL);

    rc = MQTTClient_connect(client, &conn_opts);

    if (rc != MQTTCLIENT_SUCCESS)
    {
        #ifdef HABILITA_DEBUG_VIA_PRINTF
        printf("\n\rFalha na conexao ao broker MQTT. Erro: %d\n", rc);
        #endif

        goto erro;
    }

    /* Faz subscribe nos tópicos necessários (para IPC) */
    MQTTClient_subscribe(client, MQTT_SUB_DADOS_LORAWAN_UPLINK_PARA_ESP, 0);
    MQTTClient_subscribe(client, MQTT_SUB_DAC_ESP32, 0);
    MQTTClient_subscribe(client, MQTT_SUB_ADC_RASPPI, 0);
    MQTTClient_subscribe(client, MQTT_SUB_OLED_LINHA_1, 0);
    MQTTClient_subscribe(client, MQTT_SUB_OLED_LINHA_2, 0);
    MQTTClient_subscribe(client, MQTT_SUB_OLED_LINHA_3, 0);
    MQTTClient_subscribe(client, MQTT_SUB_OLED_LINHA_4, 0);
    MQTTClient_subscribe(client, MQTT_SUB_OLED_LINHA_5, 0);
    MQTTClient_subscribe(client, MQTT_SUB_OLED_LINHA_6, 0);

    /* Abre comunicação com a porta serial */
    fd = abre_serial();
    if (fd <= 0) 
    { 
        #ifdef HABILITA_DEBUG_VIA_PRINTF
        printf("\r\n[ERRO] Impossivel abrir comunicacao com a serial.\r\n"); 
        #endif

        goto erro; 
    }

    while(1)
    {
        /* Leitura de dados da UART: le byte a byte da UART e 
           direciona cada byte à máquina de estados de recepção
           para posterior verififcação de integridade e tratamento
        */
        qtde_bytes_lidos = le_bytes(fd, &byte_lido, 1);
        if (qtde_bytes_lidos > 0)
        {
            if ( maquina_estados_recepcao(byte_lido) )
            {
                trata_dados_recebidos();
            }
        }
    }

    close(fd);
    return 0;      

erro:
    return -1;    
}

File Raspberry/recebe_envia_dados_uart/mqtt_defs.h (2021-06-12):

/* Header file com as definições de MQTT do projeto 
* Autor: Pedro Bertoleti 
*/
#ifndef MQTT_DEFS_H
#define MQTT_DEFS_H

/* Definições - endereço do Broker e ID MQTT */
#define MQTT_ADDRESS        "tcp://127.0.0.1"
#define MQTT_CLIENTID       "mqtt_id_recebe_dados_uart"  

/* Topicos para direcionar dados recebidos do Heltec ESP32 WiFi LoRa
   (para IPC com demais aplicações) */
#define MQTT_PUB_DADOS_LORAWAN_DOWNLINK_PARA_RASPPI       "mqtt_lorawan_downlink_esp32"   //topico para receber do ESP32 mensagens de downlink recebidas
#define MQTT_PUB_ADC_RASPPI                               "mqtt_adc_para_rasppi"          //topico para receber a leitura do adc vinda do esp32

/* Topicos para solicitar dados ou operações ao Heltec ESP32 WiFi LoRa
   (para IPC com demais aplicações) */
#define MQTT_SUB_DADOS_LORAWAN_UPLINK_PARA_ESP            "mqtt_lorawan_uplink_esp32"     //topico para enviar dados a serem repassados via LoRaWAN (uplink)
#define MQTT_SUB_DAC_ESP32                                "mqtt_dac_para_esp32"           //topico para enviar ao esp32 valor para escrever no DAC
#define MQTT_SUB_ADC_RASPPI                               "mqtt_adc_para_esp32"           //topico para solicitar uma leitura de adc ao esp32
#define MQTT_SUB_OLED_LINHA_1                             "mqtt_oled_linha1_esp32"        //topico para enviar mensagem a ser escrita na linha 1 do OLED do ESP32
#define MQTT_SUB_OLED_LINHA_2                             "mqtt_oled_linha2_esp32"        //topico para enviar mensagem a ser escrita na linha 2 do OLED do ESP32
#define MQTT_SUB_OLED_LINHA_3                             "mqtt_oled_linha3_esp32"        //topico para enviar mensagem a ser escrita na linha 3 do OLED do ESP32
#define MQTT_SUB_OLED_LINHA_4                             "mqtt_oled_linha4_esp32"        //topico para enviar mensagem a ser escrita na linha 4 do OLED do ESP32
#define MQTT_SUB_OLED_LINHA_5                             "mqtt_oled_linha5_esp32"        //topico para enviar mensagem a ser escrita na linha 5 do OLED do ESP32
#define MQTT_SUB_OLED_LINHA_6                             "mqtt_oled_linha6_esp32"        //topico para enviar mensagem a ser escrita na linha 6 do OLED do ESP32

#endif

/* Protótipos */
void publish(MQTTClient client, char* topic, char* payload);

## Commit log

2021-06-12 Primeiro commit
    [rasp_heltec_lora_hat-B_Cu.gbr, rasp_heltec_lora_hat-B_Mask.gbr, rasp_heltec_lora_hat-B_Paste.gbr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]
2021-06-14 Remoção de binário
2021-09-07 Atualizações de hardware:
    - Atualizada placa para uso com versão 2 do Heltec LoRa
    - Adicionado diodo 1N5819 para permitir funcionamento e programação simultaneos
    - Invertidos os conectores I2C para comportar módulos pequenos (exemplo: BMP180) conectaos diretamente na placa
    [rasp_heltec_lora_hat-B_Cu.gbr, rasp_heltec_lora_hat-B_Mask.gbr, rasp_heltec_lora_hat-B_Paste.gbr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]
2021-09-08 Adicionado software de controle do shield. Este software foi desenvolvido com QT.
2021-09-09 Atualizações:
    - Eliminada mensagem de confirmação de envio LoRaWAN (devido a conflito com topico de mensagem de downlink LoRaWAN)
    - Acrescentado local para exibir mensagens recebidas de downlink LoRaWAN no software feito em QT
